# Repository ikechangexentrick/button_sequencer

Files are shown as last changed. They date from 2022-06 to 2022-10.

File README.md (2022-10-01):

# button sequencer
4 channel gate sequencer

front panel
front pcb view 
rear pcb view

### [schematic](https://raw.githubusercontent.com/ikechangexentrick/button_sequencer/master/hw/button_sequencer_v1_schematic.pdf)

## Prerequisites

### Hardware
- ProMicro (Arduino micro clone)

### Software (Arduino libraries)
- [button](https://github.com/ikechangexentrick/button)
- [MsTimer2](https://github.com/PaulStoffregen/MsTimer2)

## Build instruction

... to be written ...

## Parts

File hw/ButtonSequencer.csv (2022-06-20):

Reference | Quantity | Value | Footprint | Datasheet
C1 C2 C5 C6 C7 | 5 | 0.1u | Capacitor_THT:C_Axial_L3.8mm_D2.6mm_P7.50mm_Horizontal | ~
C3 C4 | 2 | 100u | Capacitor_THT:CP_Radial_D6.3mm_P2.50mm | ~
D1 | 1 | clock | LED_THT:LED_D4.0mm | ~
D10 | 1 | gate4 | LED_THT:LED_D4.0mm | ~
D2 D3 | 2 | select4 | LED_THT:LED_D4.0mm | ~
D4 | 1 | select3 | LED_THT:LED_D4.0mm | ~
D5 | 1 | select2 | LED_THT:LED_D4.0mm | ~
D6 | 1 | select1 | LED_THT:LED_D4.0mm | ~
D7 | 1 | gate1 | LED_THT:LED_D4.0mm | ~
D8 | 1 | gate2 | LED_THT:LED_D4.0mm | ~
D9 | 1 | gate3 | LED_THT:LED_D4.0mm | ~
J1 | 1 | clock_in | Attenuverter:mono_jack_3.5mm | ~
J2 | 1 | gate_out_1 | Attenuverter:mono_jack_3.5mm | ~
J3 | 1 | gate_out_2 | Attenuverter:mono_jack_3.5mm | ~
J4 | 1 | gate_out_3 | Attenuverter:mono_jack_3.5mm | ~
J5 | 1 | gate_out_4 | Attenuverter:mono_jack_3.5mm | ~
J6 | 1 | power_bus | Connector_PinHeader_2.54mm:PinHeader_2x05_P2.54mm_Horizontal | ~
J7 J8 | 2 | Conn_02x09_Odd_Even | Connector_PinHeader_2.54mm:PinHeader_2x09_P2.54mm_Vertical | ~
Q1 | 1 | 2SC1815 | Package_TO_SOT_THT:TO-92_Inline | https://media.digikey.com/pdf/Data%20Sheets/Toshiba%20PDFs/2SC1815.pdf
R6 R7 R8 R9 R10 R15 R16 R17 R18 | 9 | 1k | Resistor_THT:R_Axial_DIN0207_L6.3mm_D2.5mm_P2.54mm_Vertical | ~
R11 R12 R13 R14 | 4 | 3.3k | Resistor_THT:R_Axial_DIN0207_L6.3mm_D2.5mm_P2.54mm_Vertical | ~
R19 R20 R21 | 3 | 100k | Resistor_THT:R_Axial_DIN0207_L6.3mm_D2.5mm_P2.54mm_Vertical | ~
R1 R2 R3 R4 R5 R22 R23 R24 R25 R26 R27 R28 R29 R30 | 14 | 10k | Resistor_THT:R_Axial_DIN0207_L6.3mm_D2.5mm_P2.54mm_Vertical | ~
SW1 | 1 | Rotary_Encoder | Rotary_Encoder:RotaryEncoder_Alps_EC12E_Vertical_H20mm | ~
SW2 | 1 | enter | Connector_PinHeader_2.54mm:PinHeader_1x02_P2.54mm_Vertical | ~
SW3 | 1 | func2 | Attenuverter:push_button | ~
SW4 | 1 | function | Attenuverter:push_button | ~
SW5 | 1 | SW_Push | Button_Switch_THT:SW_PUSH_6mm | ~
U1 | 1 | TL074 | Package_DIP:DIP-14_W7.62mm | http://www.ti.com/lit/ds/symlink/tl071.pdf
U2 | 1 | ProMicro | ClockGenerator:Pro_Micro_Top_side_Up
U3 | 1 | 74HC595 | Package_DIP:DIP-16_W7.62mm | http://www.ti.com/lit/ds/symlink/sn74hc595.pdf

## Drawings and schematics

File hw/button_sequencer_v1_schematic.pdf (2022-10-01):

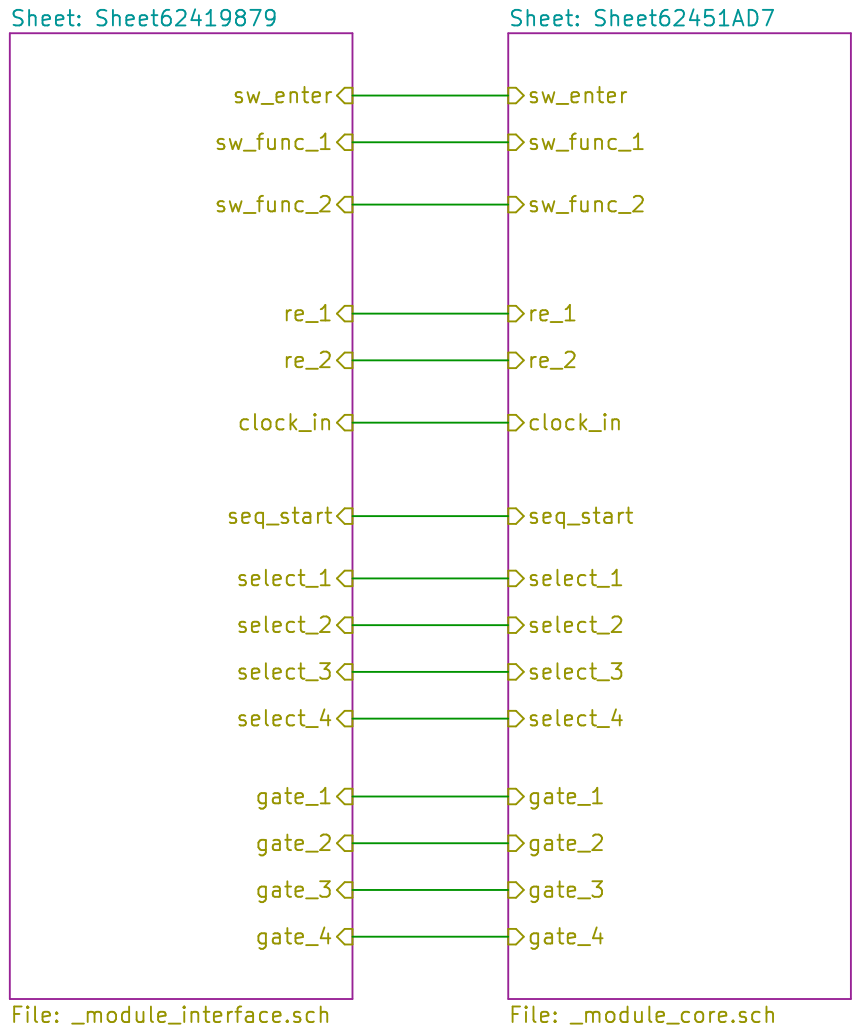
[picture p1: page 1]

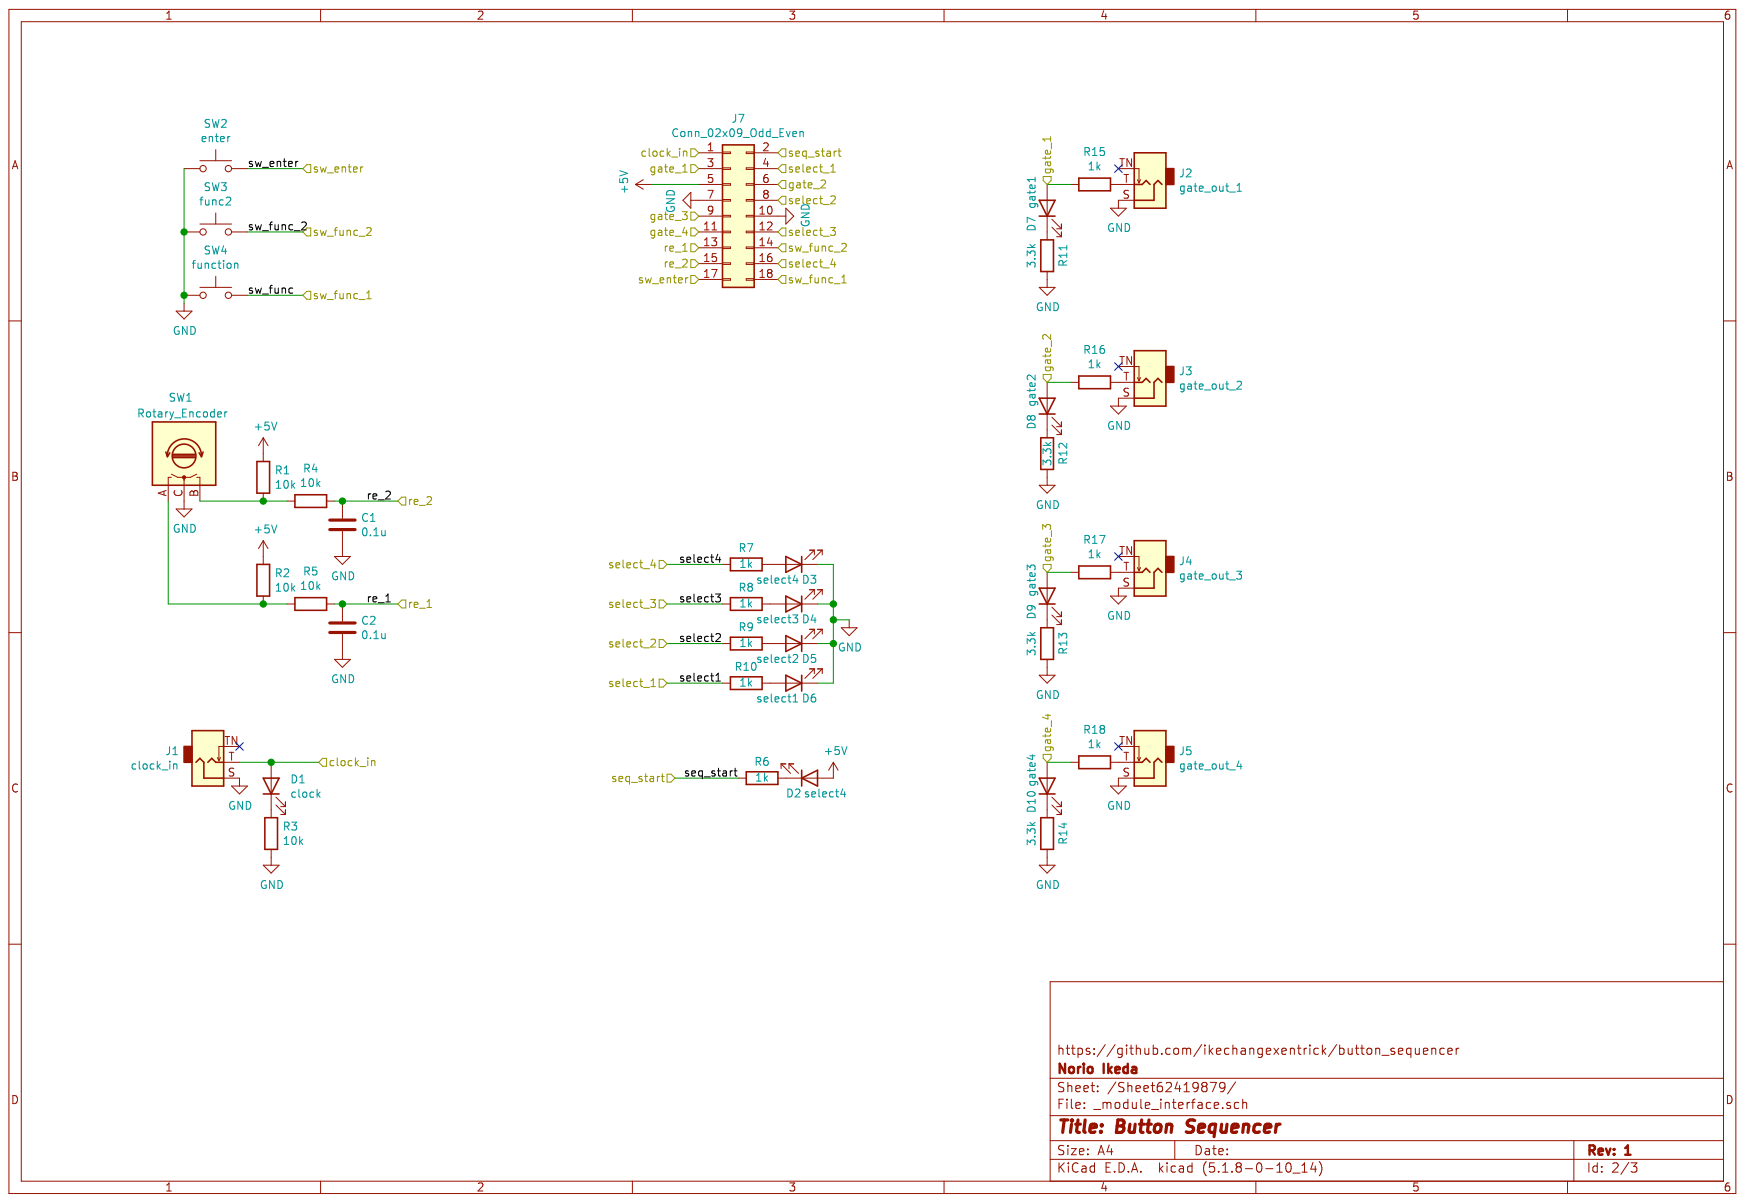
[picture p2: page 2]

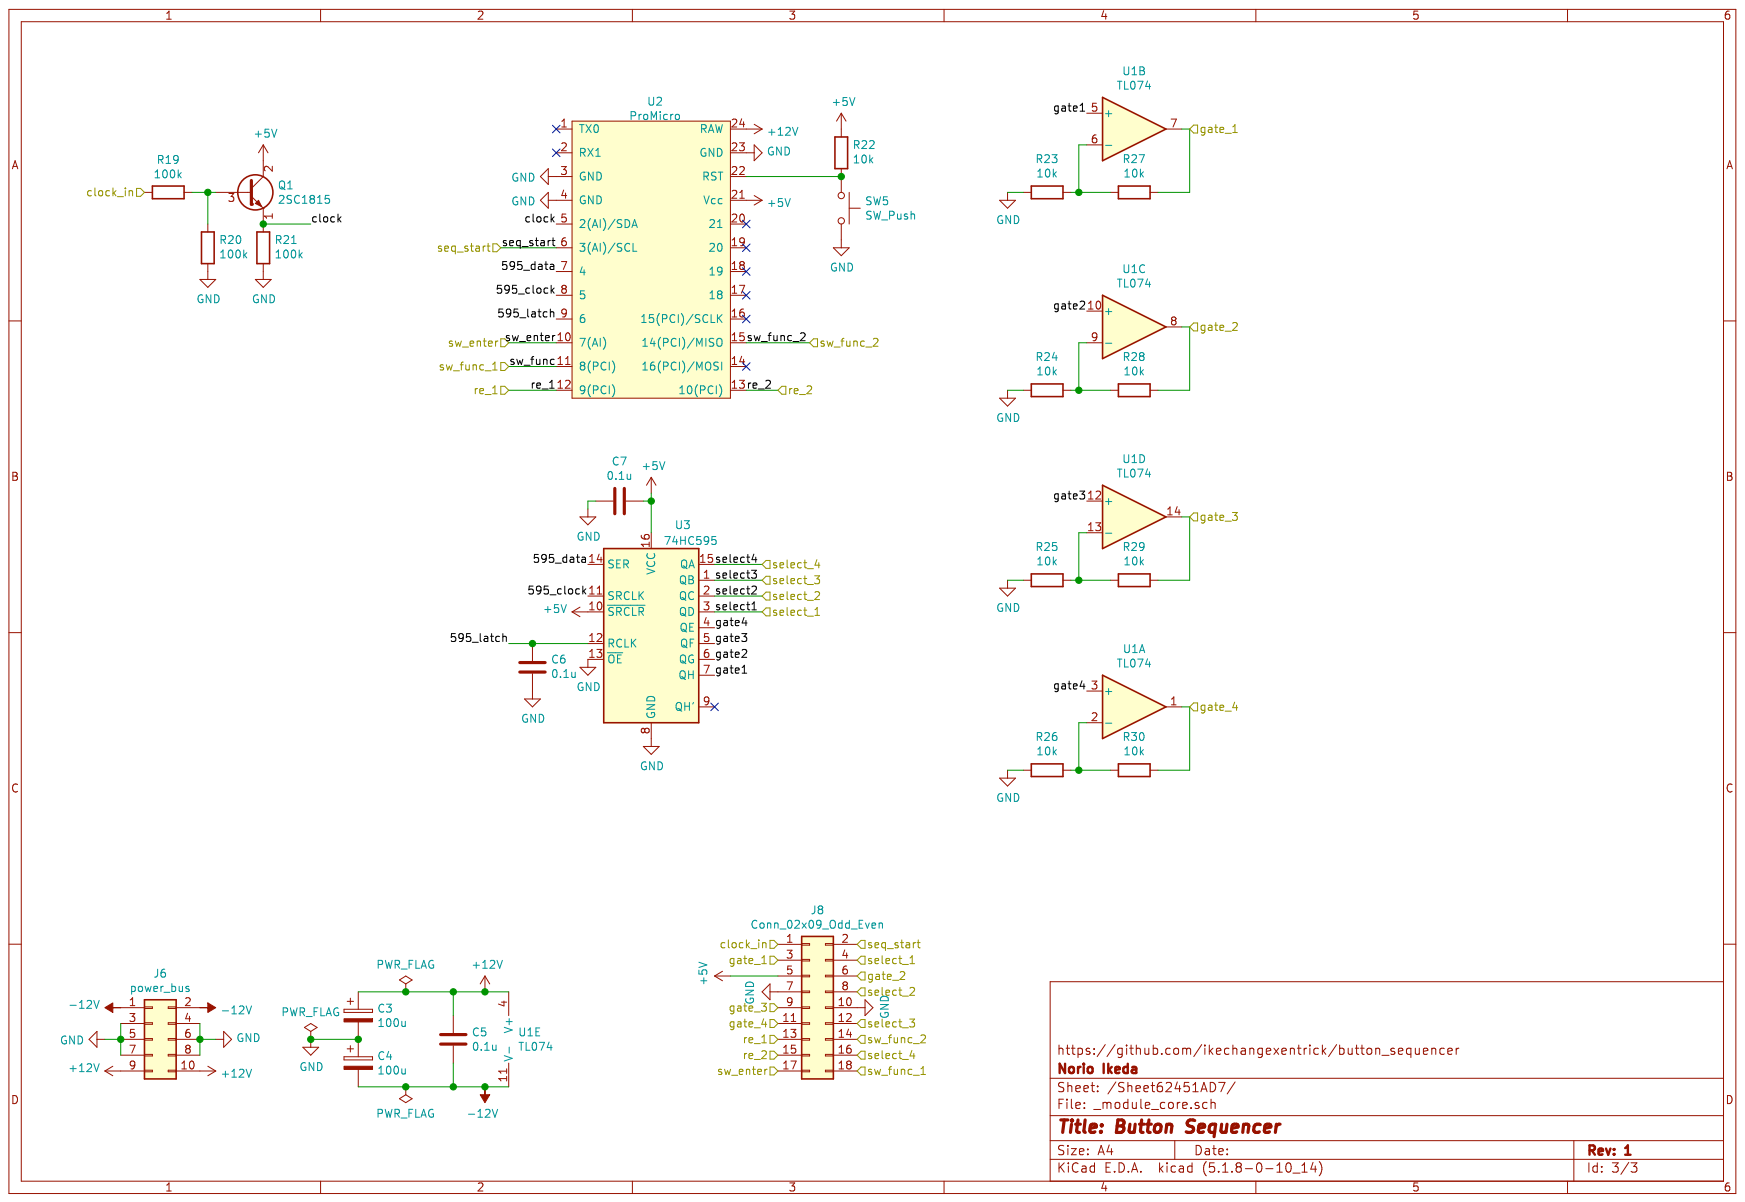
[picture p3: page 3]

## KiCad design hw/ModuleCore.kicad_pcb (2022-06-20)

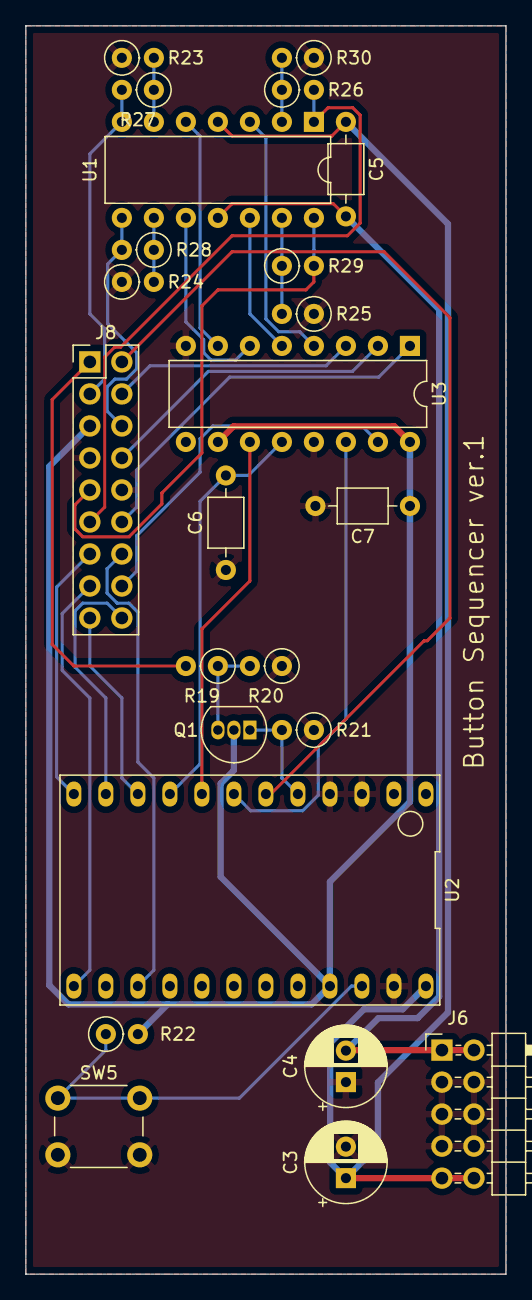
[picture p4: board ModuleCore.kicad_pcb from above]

Board: 2 copper layers, 38.1 x 99.1 mm, 24 parts (0 on the bottom side), 33 nets.

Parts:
C3, C4: 100u; CP_Radial_D6.3mm_P2.50mm
C5, C6, C7: 0.1u; C_Axial_L3.8mm_D2.6mm_P7.50mm_Horizontal
J6: power_bus; PinHeader_2x05_P2.54mm_Horizontal
J8: Conn_02x09_Odd_Even; PinHeader_2x09_P2.54mm_Vertical
Q1: 2SC1815; TO-92_Inline
R19, R20, R21: 100k; R_Axial_DIN0207_L6.3mm_D2.5mm_P2.54mm_Vertical
R22, R23, R24, R25, R26, R27, R28, R29, R30: 10k; R_Axial_DIN0207_L6.3mm_D2.5mm_P2.54mm_Vertical
SW5: SW_Push; SW_PUSH_6mm
U1: TL074; DIP-14_W7.62mm
U2: ProMicro; Pro_Micro_Top_side_Up
U3: 74HC595; DIP-16_W7.62mm

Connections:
+5V: C7.1, J8.5, Q1.2, R22.2, U2.21, U3.10, U3.16
+12V: C3.1, C5.1, J6.9, J6.10, U1.4, U2.24
-12V: C4.2, C5.2, J6.1, J6.2, U1.11
/Sheet62451AD7/595_clock: U2.8, U3.11
/Sheet62451AD7/595_data: U2.7, U3.14
/Sheet62451AD7/595_latch: C6.2, U2.9, U3.12
/Sheet62451AD7/clock: Q1.1, R21.2, U2.5
/Sheet62451AD7/clock_in: J8.1, R19.2
/Sheet62451AD7/gate1: U1.5, U3.7
/Sheet62451AD7/gate2: U1.10, U3.6
/Sheet62451AD7/gate3: U1.12, U3.5
/Sheet62451AD7/gate4: U1.3, U3.4
/Sheet62451AD7/gate_1: J8.3, R27.2, U1.7
/Sheet62451AD7/gate_2: J8.6, R28.2, U1.8
/Sheet62451AD7/gate_3: J8.9, R29.2, U1.14
/Sheet62451AD7/gate_4: J8.11, R30.2, U1.1
/Sheet62451AD7/re_1: J8.13, U2.12
/Sheet62451AD7/re_2: J8.15, U2.13
/Sheet62451AD7/select_1: J8.4, U3.3
/Sheet62451AD7/select_2: J8.8, U3.2
/Sheet62451AD7/select_3: J8.12, U3.1
/Sheet62451AD7/select_4: J8.16, U3.15
/Sheet62451AD7/seq_start: J8.2, U2.6
/Sheet62451AD7/sw_enter: J8.17, U2.10
/Sheet62451AD7/sw_func_1: J8.18, U2.11
/Sheet62451AD7/sw_func_2: J8.14, U2.15
GND: C3.2, C4.1, C6.1, C7.2, J6.3, J6.4, J6.5, J6.6, J6.7, J6.8, J8.7, J8.10, R20.1, R21.1, R23.1, R24.1, R25.1, R26.1, SW5.2, U2.3, U2.4, U2.23, U3.8, U3.13
unnamed: Q1.3, R19.1, R20.2
unnamed: R22.1, SW5.1, U2.22
unnamed: R23.2, R27.1, U1.6
unnamed: R24.2, R28.1, U1.9
unnamed: R25.2, R29.1, U1.13
unnamed: R26.2, R30.1, U1.2

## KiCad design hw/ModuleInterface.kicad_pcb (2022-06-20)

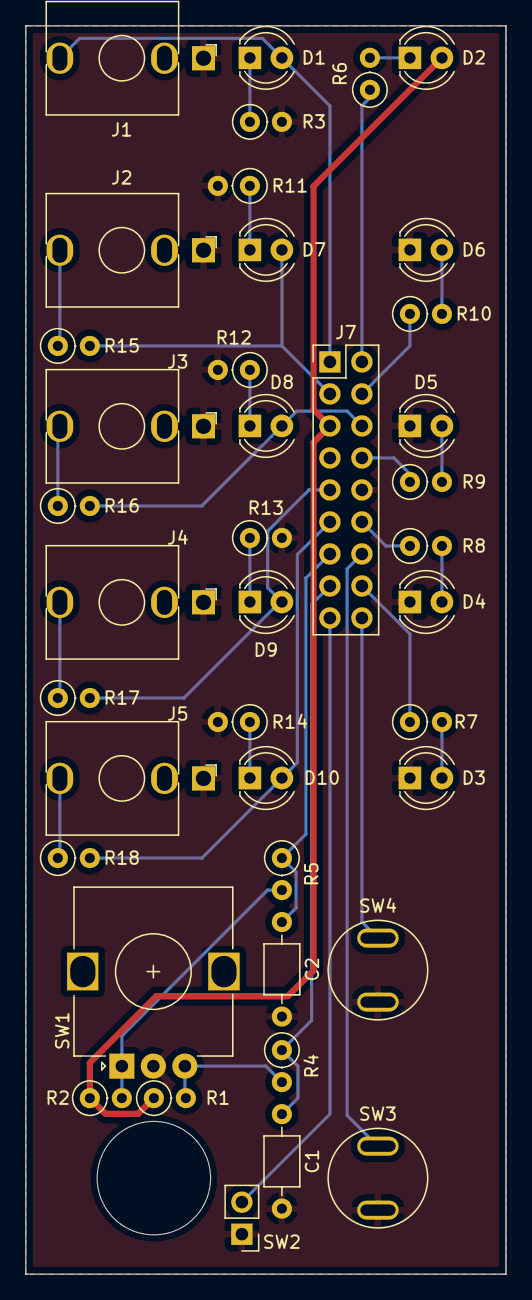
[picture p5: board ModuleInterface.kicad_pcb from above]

Board: 2 copper layers, 38.1 x 99.1 mm, 40 parts (0 on the bottom side), 33 nets.

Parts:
C1, C2: 0.1u; C_Axial_L3.8mm_D2.6mm_P7.50mm_Horizontal
D1: clock; LED_D4.0mm
D2, D3: select4; LED_D4.0mm
D4: select3; LED_D4.0mm
D5: select2; LED_D4.0mm
D6: select1; LED_D4.0mm
D7: gate1; LED_D4.0mm
D8: gate2; LED_D4.0mm
D9: gate3; LED_D4.0mm
D10: gate4; LED_D4.0mm
J1: clock_in; mono_jack_3.5mm
J2: gate_out_1; mono_jack_3.5mm
J3: gate_out_2; mono_jack_3.5mm
J4: gate_out_3; mono_jack_3.5mm
J5: gate_out_4; mono_jack_3.5mm
J7: Conn_02x09_Odd_Even; PinHeader_2x09_P2.54mm_Vertical
R1, R2, R3, R4, R5: 10k; R_Axial_DIN0207_L6.3mm_D2.5mm_P2.54mm_Vertical
R6, R7, R8, R9, R10, R15, R16, R17, R18: 1k; R_Axial_DIN0207_L6.3mm_D2.5mm_P2.54mm_Vertical
R11, R12, R13, R14: 3.3k; R_Axial_DIN0207_L6.3mm_D2.5mm_P2.54mm_Vertical
SW1: Rotary_Encoder; RotaryEncoder_Alps_EC12E_Vertical_H20mm
SW2: enter; PinHeader_1x02_P2.54mm_Vertical
SW3: func2; push_button
SW4: function; push_button

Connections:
+5V: D2.2, J7.5, R1.1, R2.1
/Sheet62419879/clock_in: D1.2, J1.T, J7.1
/Sheet62419879/gate_1: D7.2, J7.3, R15.2
/Sheet62419879/gate_2: D8.2, J7.6, R16.2
/Sheet62419879/gate_3: D9.2, J7.9, R17.2
/Sheet62419879/gate_4: D10.2, J7.11, R18.2
/Sheet62419879/re_1: C2.1, J7.13, R5.1
/Sheet62419879/re_2: C1.1, J7.15, R4.1
/Sheet62419879/select_1: J7.4, R10.1
/Sheet62419879/select_2: J7.8, R9.1
/Sheet62419879/select_3: J7.12, R8.1
/Sheet62419879/select_4: J7.16, R7.1
/Sheet62419879/seq_start: J7.2, R6.1
/Sheet62419879/sw_enter: J7.17, SW2.2
/Sheet62419879/sw_func_1: J7.18, SW4.2
/Sheet62419879/sw_func_2: J7.14, SW3.2
GND: C1.2, C2.2, D3.1, D4.1, D5.1, D6.1, J1.S, J2.S, J3.S, J4.S, J5.S, J7.7, J7.10, R3.2, R11.2, R12.2, R13.2, R14.2, SW1.C, SW2.1, SW3.1, SW4.1
unnamed: D1.1, R3.1
unnamed: D2.1, R6.2
unnamed: D3.2, R7.2
unnamed: D4.2, R8.2
unnamed: D5.2, R9.2
unnamed: D6.2, R10.2
unnamed: D7.1, R11.1
unnamed: D8.1, R12.1
unnamed: D9.1, R13.1
unnamed: D10.1, R14.1
unnamed: J2.T, R15.1
unnamed: J3.T, R16.1
unnamed: J4.T, R17.1
unnamed: J5.T, R18.1
unnamed: R1.2, R4.2, SW1.B
unnamed: R2.2, R5.2, SW1.A

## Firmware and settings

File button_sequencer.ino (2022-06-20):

#include "button.h"
#include "MsTimer2.h"

#undef DEBUG

static const int SERIAL_BAUD_RATE = 9600;

static const size_t BUFLEN = 64;
char msg_buf[BUFLEN];

template <typename... Args>
void serial_log(const char *fmt, Args... args)
{
	snprintf(msg_buf, BUFLEN, fmt, args...);
	Serial.println( msg_buf );
}

//  -----------------------------------------------

// clock in
const static int PIN_EXT_CLOCK = 2; // attachInterrupt

// 74HC595
const static int PIN_595_LATCH = 6;
const static int PIN_595_CLOCK = 5;
const static int PIN_595_DATA = 4;

void emit(unsigned char v)
{
	digitalWrite(PIN_595_LATCH, LOW);
	shiftOut(PIN_595_DATA, PIN_595_CLOCK, LSBFIRST, v);
	digitalWrite(PIN_595_LATCH, HIGH);
}

// buttons and rotary encoder
const static int PIN_TRIGGER_BUTTON = 7; // attachInterrupt
const static int PIN_FUNC_BUTTON = 8; // pin-change-interrupt
const static int PIN_FUNC2_BUTTON = 14; // pin-change-interrupt
const static int PIN_ROTARY_1 = 9; // pin-change-interrupt
const static int PIN_ROTARY_2 = 10; // pin-change-interrupt

const static int PIN_SEQ_START = 3;

const static size_t TIMER_UNIT = 25; // ms

static const size_t SEQ_MAX = 64;
static const size_t SLOT_MAX = 4;
bool sequence[SLOT_MAX][SEQ_MAX];
bool rtg[SLOT_MAX][SEQ_MAX];

static const size_t CONFIG_MAX = 3;
int config[SLOT_MAX] = {
	0			// sequence length 0..16, 1..32, 2..64
	, 0		// ratchetting (retriggering) speed 0..1, 1..2, 2..3 x TIMER_UNIT ms
	, 0		// reserve
	, 0		// reserve
};

// TODO: micro timing delay 

size_t get_sequence_length()
{
	const auto &v = config[0];
	if (v == 0) return 16;
	else if (v == 1) return 32;
	else if (v == 2) return SEQ_MAX;
}

size_t get_ratchetting_interval()
{
	const auto &v = config[1];
	if (v == 0) return 0;
	else if (v == 1) return 2;
	else if (v == 2) return 4;
}


int cnt_seq;

volatile bool config_mode = false;

class OutputManager
{
public:
	void update_current_slot(size_t slot)
	{
		current_slot = slot;

		auto new_data = prev_data & 0xf;
		new_data |= ((1 << current_slot) & 0xf) << 4;

		emit(new_data);
		prev_data = new_data;
	}

	size_t get_current_slot() const
	{ return current_slot; }

	void out_sequence(size_t cnt_seq, bool (*arr)[SEQ_MAX])
	{
		unsigned char new_value = 0xf0;
		for (size_t i = 0; i < SLOT_MAX; ++i)
			if (arr[i][cnt_seq]) new_value |= 1 << i;

		prev_data |= 0x0f;
		prev_data &= new_value;
		emit(prev_data);
	}

	void clear_sequence()
	{
		prev_data &= 0xf0;
		emit(prev_data);
	}

	void blink(bool b)
	{
		auto new_data = prev_data & 0xf;

		// overlay rtgpegio on "prev_data"
		for (size_t i = 0; i < SLOT_MAX; ++i) {
			if (rtg[i][cnt_seq]) {
				if (!b) new_data |= ((1 << i) & 0xf);
				else new_data &= ~((1 << i) & 0xf);
			}
		}
		prev_data = new_data;

		if (!config_mode) {
			// reset indicators when exited config mode
			update_current_slot(current_slot);
			//digitalWrite(PIN_SEQ_START, HIGH);
			return;
		}

		// show config value in "cycle" LED.
		switch (config[current_slot]) {
			case 0 :
				digitalWrite(PIN_SEQ_START, HIGH);
				break;
			case 1 :
				if (b) digitalWrite(PIN_SEQ_START, HIGH);
				else digitalWrite(PIN_SEQ_START, LOW);
				break;
			case 2 :
				digitalWrite(PIN_SEQ_START, LOW);
				break;
		}

		// slot selector blinking
		if (!b) {
			new_data |= ((1 << current_slot) & 0xf) << 4;
		} 

		emit(new_data);
		prev_data = new_data;
	}

private:
	size_t current_slot = 0;

	// MSB [slot3 slot2 slot1 slot0][seq3 seq2 seq1 seq0] LSB
	unsigned char prev_data = 0;
};

OutputManager om;

bool btn_clr;

class Button_trigger : public Button
{
public:
	Button_trigger(int pin)
		: Button(pin)
	{}

private:
	virtual void onButton(int state) override
	{
		const auto current_slot = om.get_current_slot();
		if (state == 1) {
			if ( digitalRead(PIN_FUNC_BUTTON) == LOW) {
#ifdef DEBUG
				serial_log("Button_trigger::onButton: clear");
#endif // DEBUG
				for (int i = 0; i < SEQ_MAX; ++i) {
					sequence[current_slot][i] = false;
					rtg[current_slot][i] = false;
				}

			} else if ( digitalRead(PIN_FUNC2_BUTTON) == LOW ) {
#ifdef DEBUG
				serial_log("Button_trigger::onButton: rtgeggio");
#endif // DEBUG
				if (!config_mode) rtg[current_slot][cnt_seq] = true;

			} else {
				if (config_mode) {
					auto c = config[current_slot];
					c += 1;
					if (c >= CONFIG_MAX) c = 0;
					config[current_slot] = c;
#ifdef DEBUG
					serial_log("Button_trigger::onButton: config: %d: %d", current_slot, c);
#endif // DEBUG
				} else {
					// normal mode
					sequence[current_slot][cnt_seq] = true;
				}

			}

		}
	}
};

class Button_func : public Button
{
public:
	Button_func(int pin)
		: Button(pin)
	{}

private:
	virtual void onButton(int state) override
	{
		const auto current_slot = om.get_current_slot();
		if (state == 1) {
			if ( digitalRead(PIN_FUNC2_BUTTON) == LOW ) {
				config_mode = !config_mode;
				if (config_mode) {
#ifdef DEBUG
					serial_log("Button_func::onButton: config mode");
#endif // DEBUG
				} else {
#ifdef DEBUG
					serial_log("Button_func::onButton: normal mode");
#endif // DEBUG
				}

			} else {
#ifdef DEBUG
				serial_log("Button_func::onButton: copy");
#endif // DEBUG
				for (int i = 0; i < get_sequence_length()/2; ++i) {
					sequence[current_slot][i+get_sequence_length()/2]
					 	= sequence[current_slot][i];
					rtg[current_slot][i+get_sequence_length()/2]
					 	= rtg[current_slot][i];
				}
			}
		}

	}
};


class RE_cmd : public RotarySwitch
{
public:
	RE_cmd(int pin_1, int pin_2)
		: RotarySwitch(pin_1, pin_2)
	{}

private:
	virtual void onRotarySW(RSW_DIR dir) override
	{
		auto slot = om.get_current_slot();

		if (dir == CW) {
			if (slot < SLOT_MAX-1) slot += 1;
		} else {
			if (slot > 0) slot -= 1;
		}

		om.update_current_slot(slot);
	}
};


void onClock()
{
	if (digitalRead(PIN_EXT_CLOCK) == HIGH) {
		// rising edge
		if (!config_mode && cnt_seq == 0) {
#ifdef DEBUG
			serial_log("cycle");
#endif // DEBUG
			digitalWrite(PIN_SEQ_START, LOW);
		}

		om.out_sequence(cnt_seq, sequence);

	} else {
		// falling edge
		if (!config_mode && cnt_seq == 0) digitalWrite(PIN_SEQ_START, HIGH);

		// quantize between previous falling edge and next falling edge
		cnt_seq += 1;
		if (cnt_seq >= get_sequence_length()) cnt_seq = 0;

		om.clear_sequence();
	}
}

Button_trigger button_t(PIN_TRIGGER_BUTTON);
void onTriggerChanged()
{
	button_t.callback();
}

RE_cmd re(PIN_ROTARY_1, PIN_ROTARY_2);
Button_func button_f(PIN_FUNC_BUTTON);
ISR(PCINT0_vect)
{
	re.callback();
	button_f.callback();
}

void print_seq(bool (*sequence)[SEQ_MAX], size_t cnt_seq)
{
	serial_log("[%d %d %d %d]"
		, sequence[0][cnt_seq] 
		, sequence[1][cnt_seq] 
		, sequence[2][cnt_seq] 
		, sequence[3][cnt_seq] 
	);
}

void onTimer()
{
	static bool blink = true;
	static size_t rtg_cnt = 0;

	rtg_cnt += 1;
	if (rtg_cnt >= get_ratchetting_interval()) rtg_cnt = 0;

	if (rtg_cnt == 0) {
		blink = !blink;
		om.blink(blink);
	}
}

void setup() {
  Serial.begin(SERIAL_BAUD_RATE);

//*
	pinMode(PIN_EXT_CLOCK, INPUT);
  attachInterrupt(digitalPinToInterrupt(PIN_EXT_CLOCK), onClock, CHANGE);
// */

	// 74HC595
	pinMode(PIN_595_LATCH, OUTPUT);
	pinMode(PIN_595_CLOCK, OUTPUT);
	pinMode(PIN_595_DATA, OUTPUT);

  pinMode(PIN_TRIGGER_BUTTON, INPUT_PULLUP);
  attachInterrupt(digitalPinToInterrupt(PIN_TRIGGER_BUTTON), onTriggerChanged, CHANGE);

  pinMode(PIN_FUNC_BUTTON, INPUT_PULLUP);
  pinMode(PIN_FUNC2_BUTTON, INPUT_PULLUP);

  pinMode(PIN_ROTARY_1, INPUT);
  pinMode(PIN_ROTARY_2, INPUT);

  pinMode(PIN_SEQ_START, OUTPUT);

	// pin-change-interrupt
	PCICR = 0;
	PCMSK0 = 
		  1 << 4 // 8 = PIN_FUNC_BUTTON
		| 1 << 5 // 9 = PIN_ROTARY_1
	;
	PCICR = 
		1 // PCIE0
	;

	btn_clr = true;

	for (int i = 0; i < SLOT_MAX; ++i) 
		for (int j = 0; j < SEQ_MAX; ++j) 
			sequence[i][j] = false;

	om.update_current_slot(0);

	MsTimer2::set(TIMER_UNIT, onTimer);
	MsTimer2::start();
}


void loop() {
}

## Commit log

2022-06-20 Modified to accomodate to the actual circuit, instead of the breadboard prototype.
2022-06-20 Appended config mode; keep press "func", then click "fill/clear" to enter. In the config mode, "slot" LED blinks. The slots correspond to config items (see below). Config value is indicated on "cycle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
    Appended ratchetting/retriggering; keep press "func", then click "enter".
2022-06-20 Software: Fixed a bug - modified to output beats when pressing Enter button.
    Hardware: appended kicad project files.
    [ButtonSequencer.csv, ButtonSequencer.kicad_pcb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]
2022-10-01 Added schematic pdf.
    [ButtonSequencer.sch, _module_core.sch, _module_interface.sch]
